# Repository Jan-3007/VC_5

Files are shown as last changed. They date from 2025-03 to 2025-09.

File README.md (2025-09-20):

# Project VC 5

Note: This project is still under development.

finished parts:
- Firmware
- PC app (basic functionality)
- schematic

under development:
- 3D model for the case
- PC app (features for better useability)

future:
- support for Linux

## General description
The aim of this project is to create an external device, which allows the user to adjust the volume of various programs on a host PC. 

## Hardware
A number of rotaries are available as input (number set to 5 within the config file of this project) and LED's and displays to show any kind of status.
The schematic for the device can be found at _Harware/schematic_.
Note: Soldering Pads in the schematic might be 0.1 mm thick, still working on a solution.

## Software
The software consists of two parts.

### 1. Firmware
The firmware is written for the Raspberry Pi RP2040. It communicates via USB with the host PC. The firmware only transmits data from the rotaries to the host PC and executes commands from the host PC. These commands can for example set the color of the LED and change the content shown on the displays.

### 2. PC application
The PC application (only Windows) acts as the executing intelligence. It takes the data from the rotaries and processes it. The volume of five different audio channels is controlled. The application can also send commands to the device to e.g. set the LED color or write information on the displays.

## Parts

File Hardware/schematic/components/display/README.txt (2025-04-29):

Thanks to thmjpr
https://grabcad.com/library/1-3-oled-module-1

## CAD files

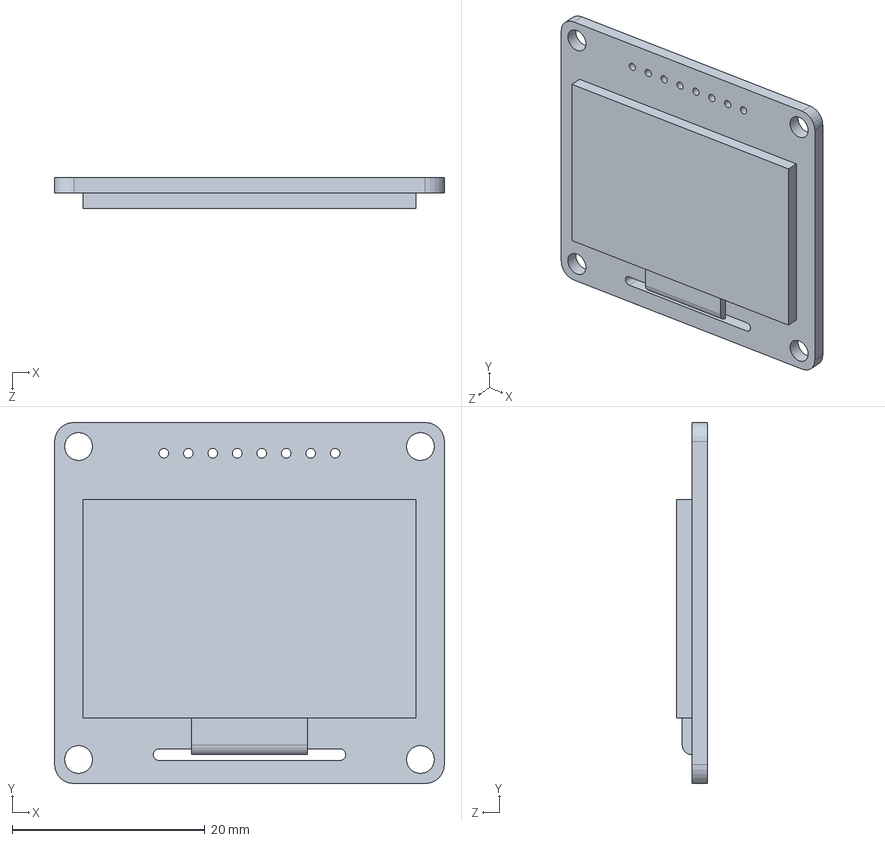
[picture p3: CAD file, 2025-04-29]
Hardware/schematic/components/display/OLED_pcb_1.3.SLDPRT
40.5 x 37.5 x 3.24 mm

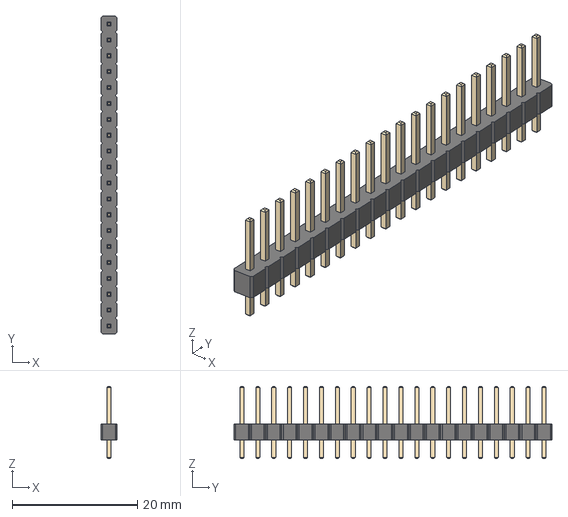
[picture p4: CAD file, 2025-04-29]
Hardware/schematic/components/pin_header/PinHeader_1x20_P2.54mm_Vertical.step
2.54 x 50.8 x 11.5 mm

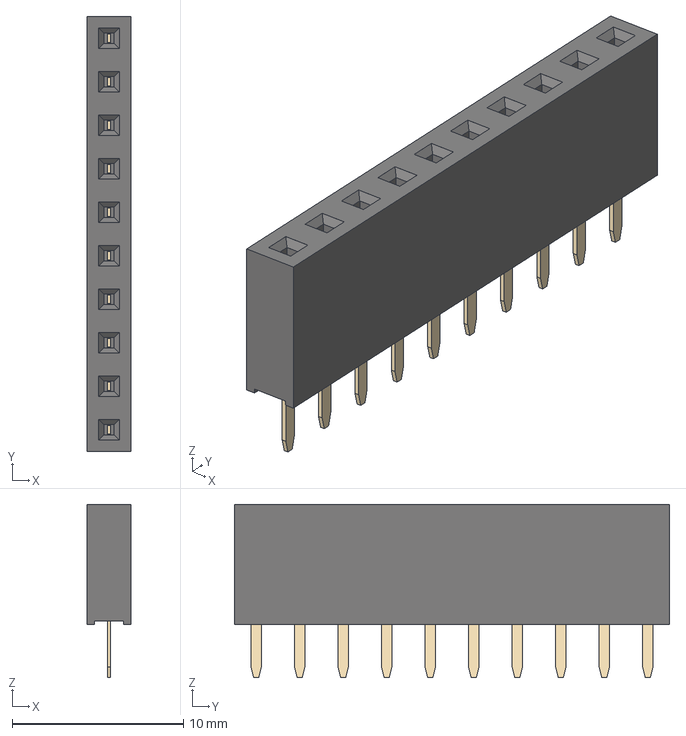
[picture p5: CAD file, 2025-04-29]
Hardware/schematic/components/pin_sockets/PinSocket_1x10_P2.54mm_Vertical.step
2.54 x 25.4 x 10.1 mm

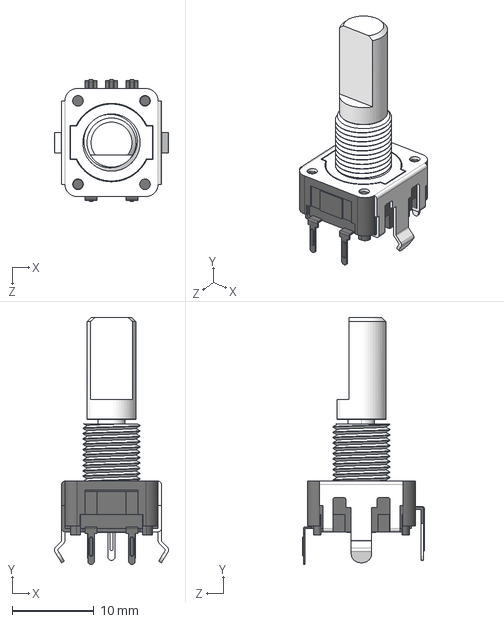
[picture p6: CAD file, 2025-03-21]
Hardware/schematic/components/rotary/PEC11R-4220F-S0024.stp
14.0 x 30.2 x 14.9 mm

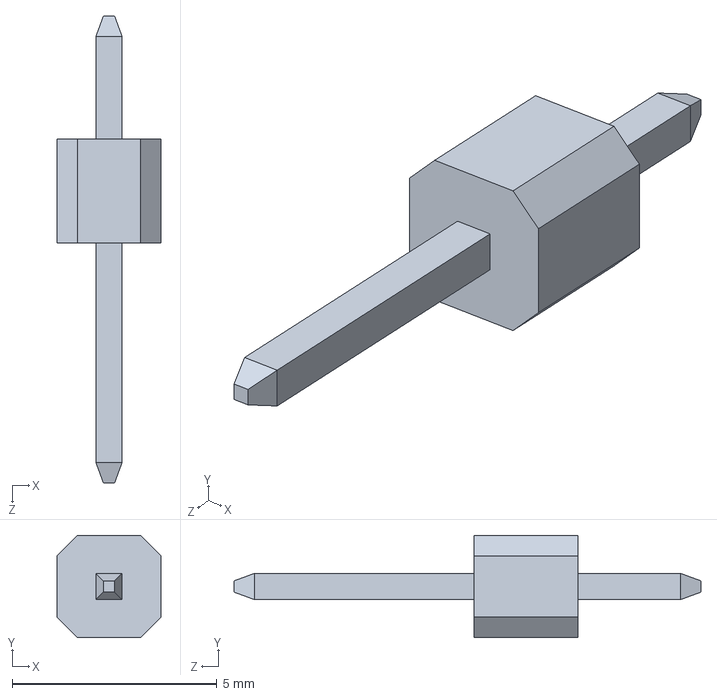
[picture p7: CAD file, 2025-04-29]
Hardware/schematic/components/display/2.54mm_pin_header.SLDPRT
2.54 x 2.50 x 11.4 mm

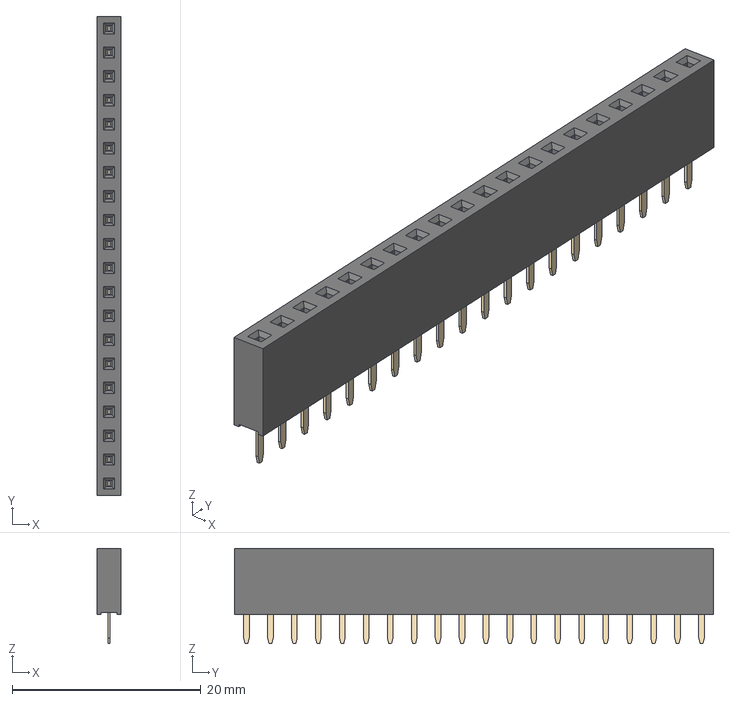
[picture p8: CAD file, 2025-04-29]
Hardware/schematic/components/pin_sockets/PinSocket_1x20_P2.54mm_Vertical.step
2.54 x 50.8 x 10.1 mm

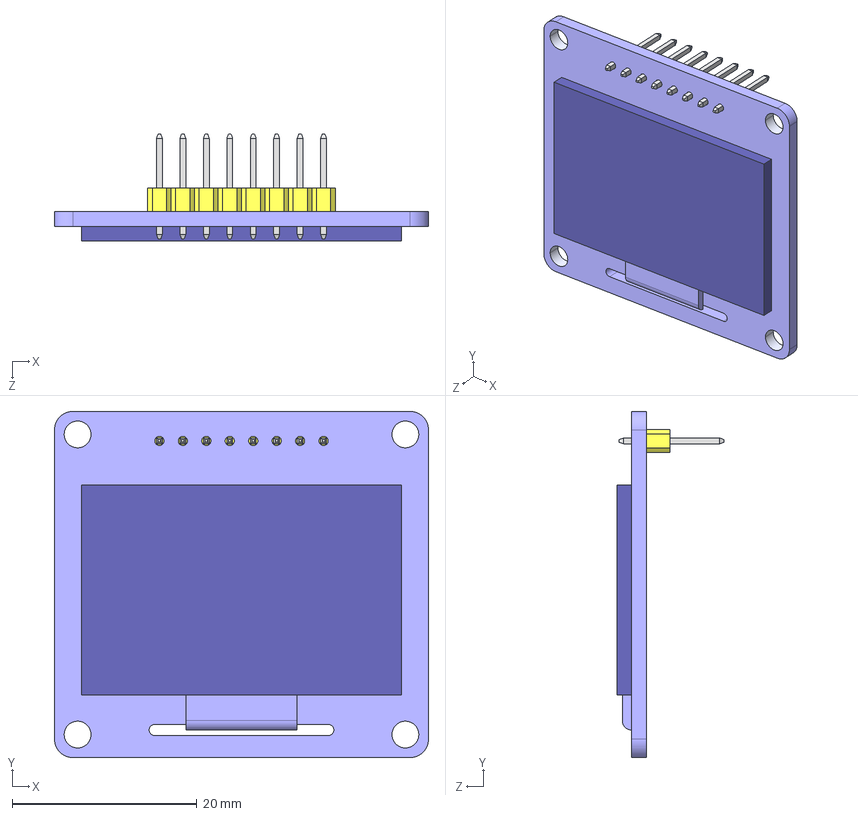
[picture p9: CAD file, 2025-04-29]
Hardware/schematic/components/display/OLED_1.3inch_sh1106.STEP
40.5 x 37.5 x 11.6 mm
OLED_pcb_1.3
2.54mm_pin_header x 8

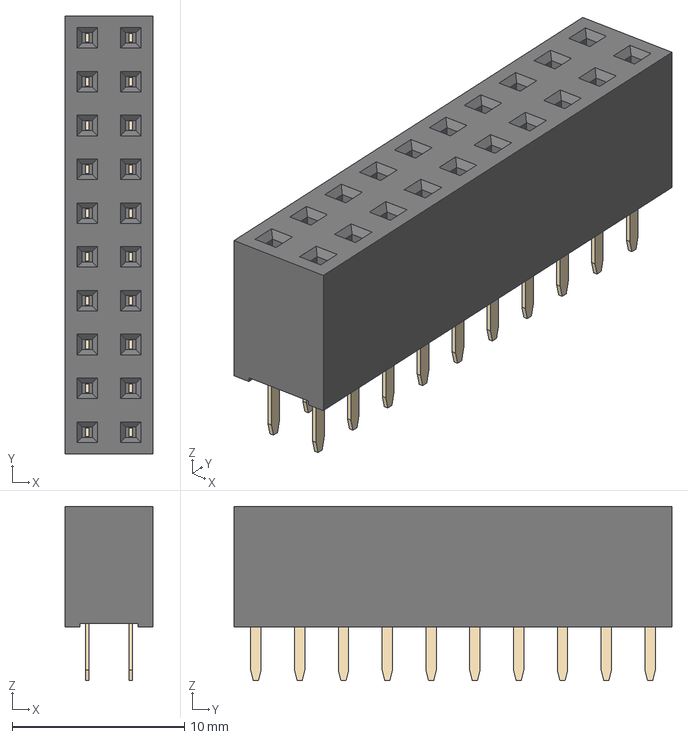
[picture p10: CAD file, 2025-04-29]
Hardware/schematic/components/pin_sockets/PinSocket_2x10_P2.54mm_Vertical.step
5.08 x 25.4 x 10.1 mm

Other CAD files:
Hardware/schematic/components/display/OLED_1.3inch_sh1106.SLDASM

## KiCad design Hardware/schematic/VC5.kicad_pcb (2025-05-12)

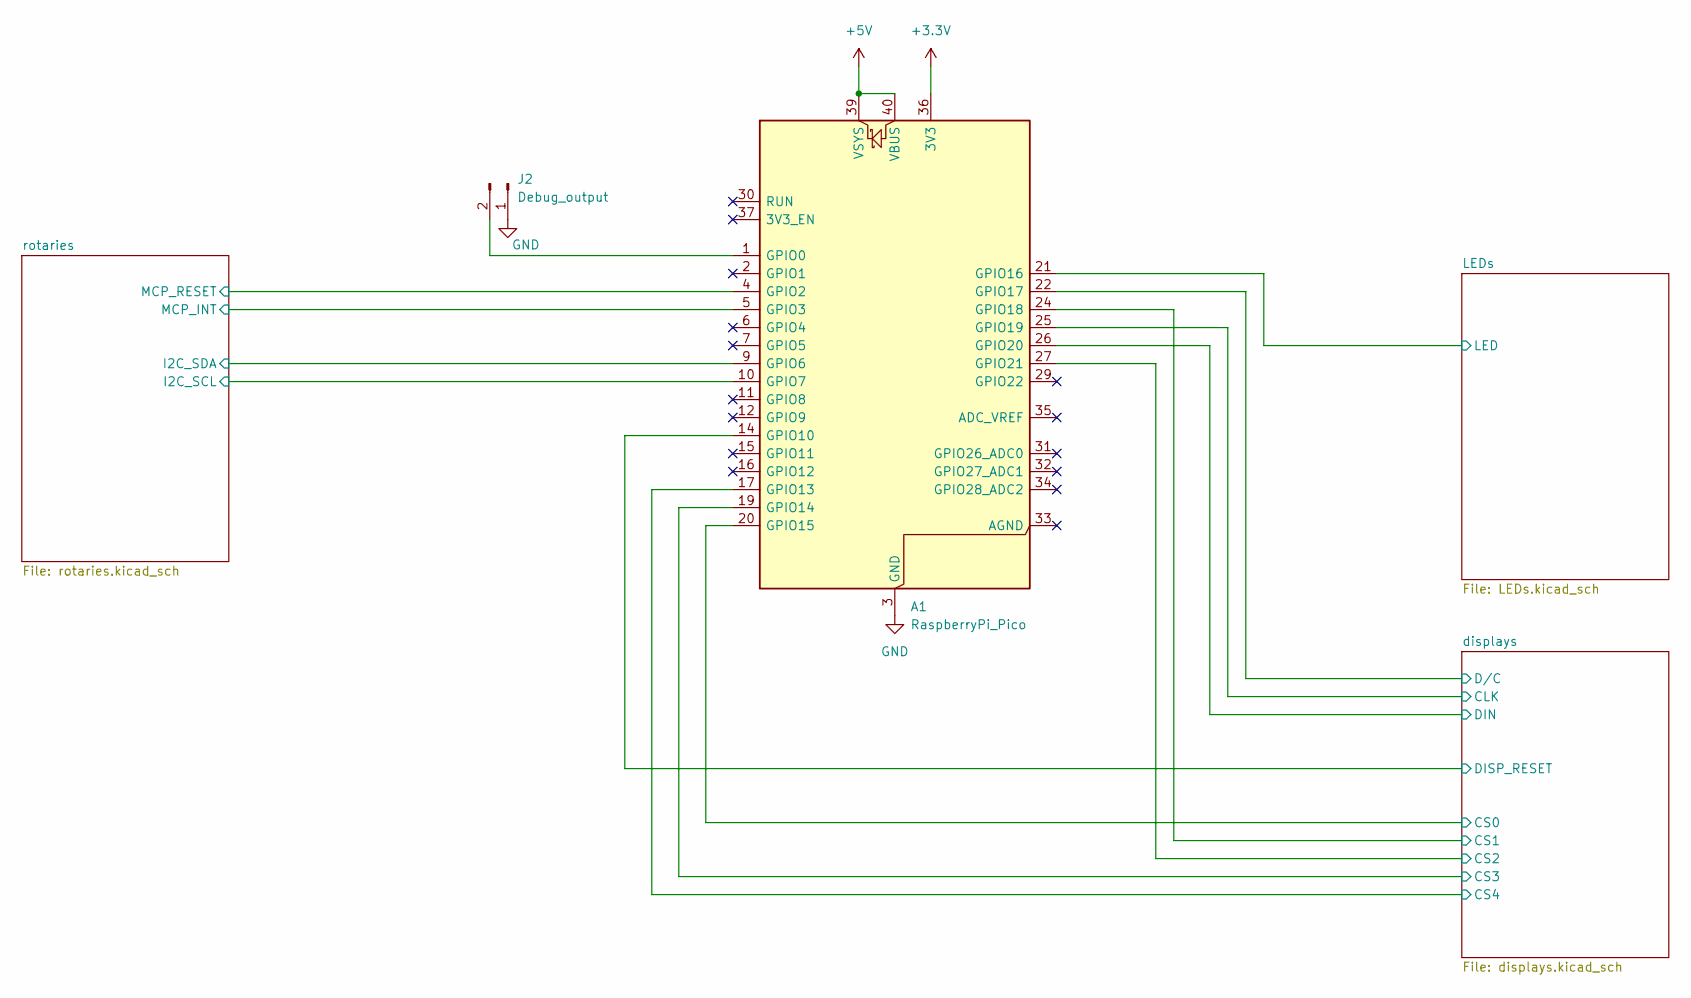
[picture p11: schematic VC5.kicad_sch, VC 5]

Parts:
A1: RaspberryPi_Pico; RaspberryPi_Pico_Common_THT_custom
J2: Debug_output; PinHeader_1x02_P2.54mm_Vertical

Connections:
+3.3V: A1.36 (3V3); also elsewhere on the board
+5V: A1.39 (VSYS), A1.40 (VBUS); also elsewhere on the board
/LEDs/LED: A1.21 (GPIO16); also elsewhere on the board
/displays/CLK: A1.25 (GPIO19); also elsewhere on the board
/displays/CS0: A1.20 (GPIO15); also elsewhere on the board
/displays/CS1: A1.24 (GPIO18); also elsewhere on the board
/displays/CS2: A1.27 (GPIO21); also elsewhere on the board
/displays/CS3: A1.19 (GPIO14); also elsewhere on the board
/displays/CS4: A1.17 (GPIO13); also elsewhere on the board
/displays/DIN: A1.26 (GPIO20); also elsewhere on the board
/displays/DISP_RESET: A1.14 (GPIO10); also elsewhere on the board
/displays/D/C: A1.22 (GPIO17); also elsewhere on the board
/rotaries/I2C_SCL: A1.10 (GPIO7); also elsewhere on the board
/rotaries/I2C_SDA: A1.9 (GPIO6); also elsewhere on the board
/rotaries/MCP_INT: A1.5 (GPIO3); also elsewhere on the board
/rotaries/MCP_RESET: A1.4 (GPIO2); also elsewhere on the board
GND: A1.3 (GND), A1.8 (GND), A1.13 (GND), A1.18 (GND), A1.23 (GND), A1.28 (GND), A1.38 (GND), J2.1; also elsewhere on the board
unnamed: A1.1 (GPIO0), J2.2

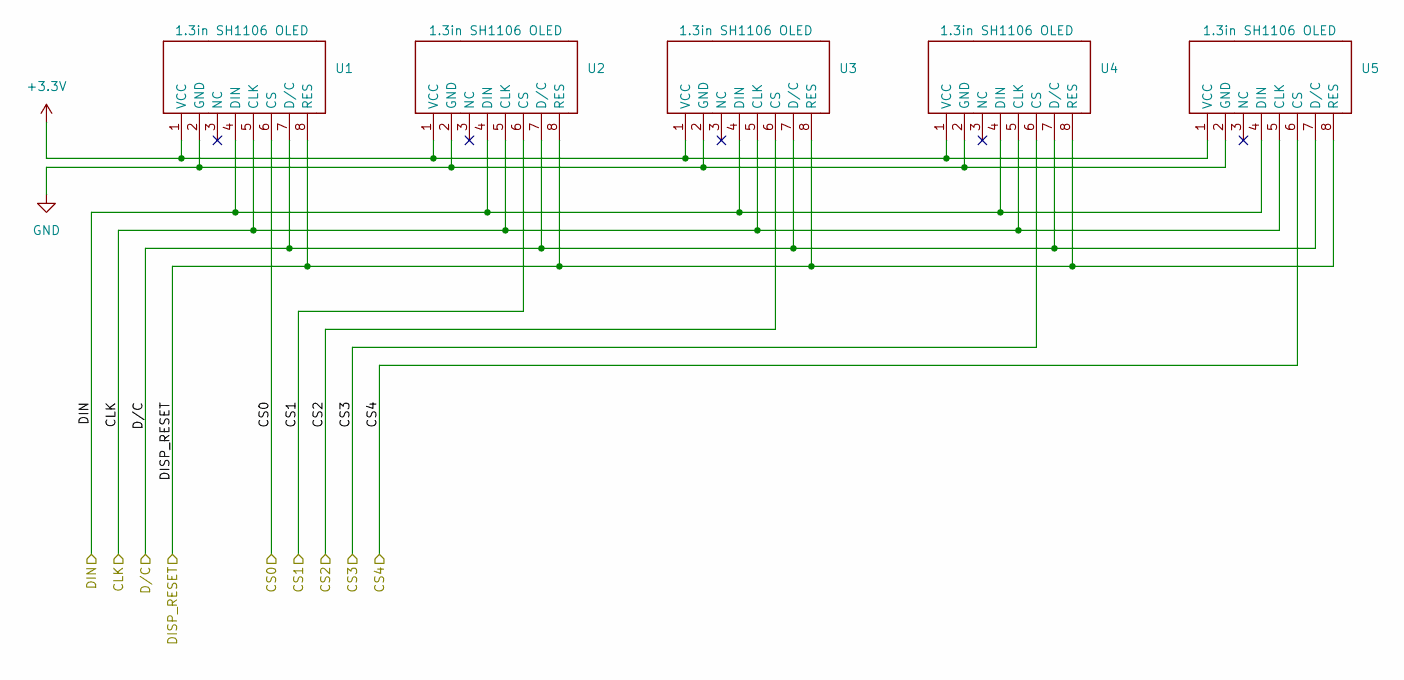
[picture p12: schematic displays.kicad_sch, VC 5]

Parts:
U1, U2, U3, U4, U5: 1.3in SH1106 OLED; PinHeader_1x08_P2.54mm_Vertical_Display

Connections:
+3.3V: U1.1 (VCC), U2.1 (VCC), U3.1 (VCC), U4.1 (VCC), U5.1 (VCC); also elsewhere on the board
/displays/CLK: U1.5 (CLK), U2.5 (CLK), U3.5 (CLK), U4.5 (CLK), U5.5 (CLK); also elsewhere on the board
/displays/CS0: U1.6 (CS); also elsewhere on the board
/displays/CS1: U2.6 (CS); also elsewhere on the board
/displays/CS2: U3.6 (CS); also elsewhere on the board
/displays/CS3: U4.6 (CS); also elsewhere on the board
/displays/CS4: U5.6 (CS); also elsewhere on the board
/displays/DIN: U1.4 (DIN), U2.4 (DIN), U3.4 (DIN), U4.4 (DIN), U5.4 (DIN); also elsewhere on the board
/displays/DISP_RESET: U1.8 (RES), U2.8 (RES), U3.8 (RES), U4.8 (RES), U5.8 (RES); also elsewhere on the board
/displays/D/C: U1.7 (D/C), U2.7 (D/C), U3.7 (D/C), U4.7 (D/C), U5.7 (D/C); also elsewhere on the board
GND: U1.2 (GND), U2.2 (GND), U3.2 (GND), U4.2 (GND), U5.2 (GND); also elsewhere on the board

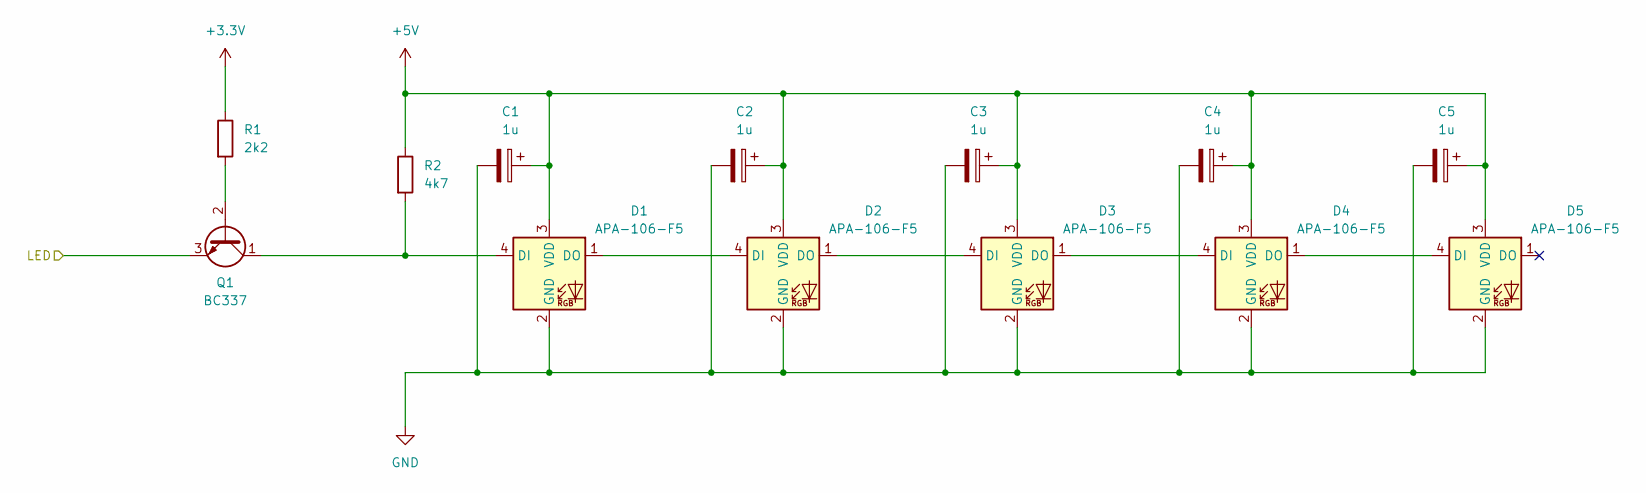
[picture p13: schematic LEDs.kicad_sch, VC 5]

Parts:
C1, C2, C3, C4, C5: 1u; CP_Radial_D5.0mm_P2.00mm
D1, D2, D3, D4, D5: APA-106-F5; LED_D5.0mm-4_RGB_Wide_Pins
Q1: BC337; TO-92_Inline
R1: 2k2; R_Axial_DIN0204_L3.6mm_D1.6mm_P7.62mm_Horizontal
R2: 4k7; R_Axial_DIN0204_L3.6mm_D1.6mm_P7.62mm_Horizontal

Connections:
+3.3V: R1.1; also elsewhere on the board
+5V: C1.1, C2.1, C3.1, C4.1, C5.1, D1.3 (VDD), D2.3 (VDD), D3.3 (VDD), D4.3 (VDD), D5.3 (VDD), R2.1; also elsewhere on the board
/LEDs/LED: Q1.3 (E); also elsewhere on the board
GND: C1.2, C2.2, C3.2, C4.2, C5.2, D1.2 (GND), D2.2 (GND), D3.2 (GND), D4.2 (GND), D5.2 (GND); also elsewhere on the board
unnamed: D1.4 (DI), Q1.1 (C), R2.2
unnamed: D1.1 (DO), D2.4 (DI)
unnamed: D2.1 (DO), D3.4 (DI)
unnamed: D3.1 (DO), D4.4 (DI)
unnamed: D4.1 (DO), D5.4 (DI)
unnamed: Q1.2 (B), R1.2

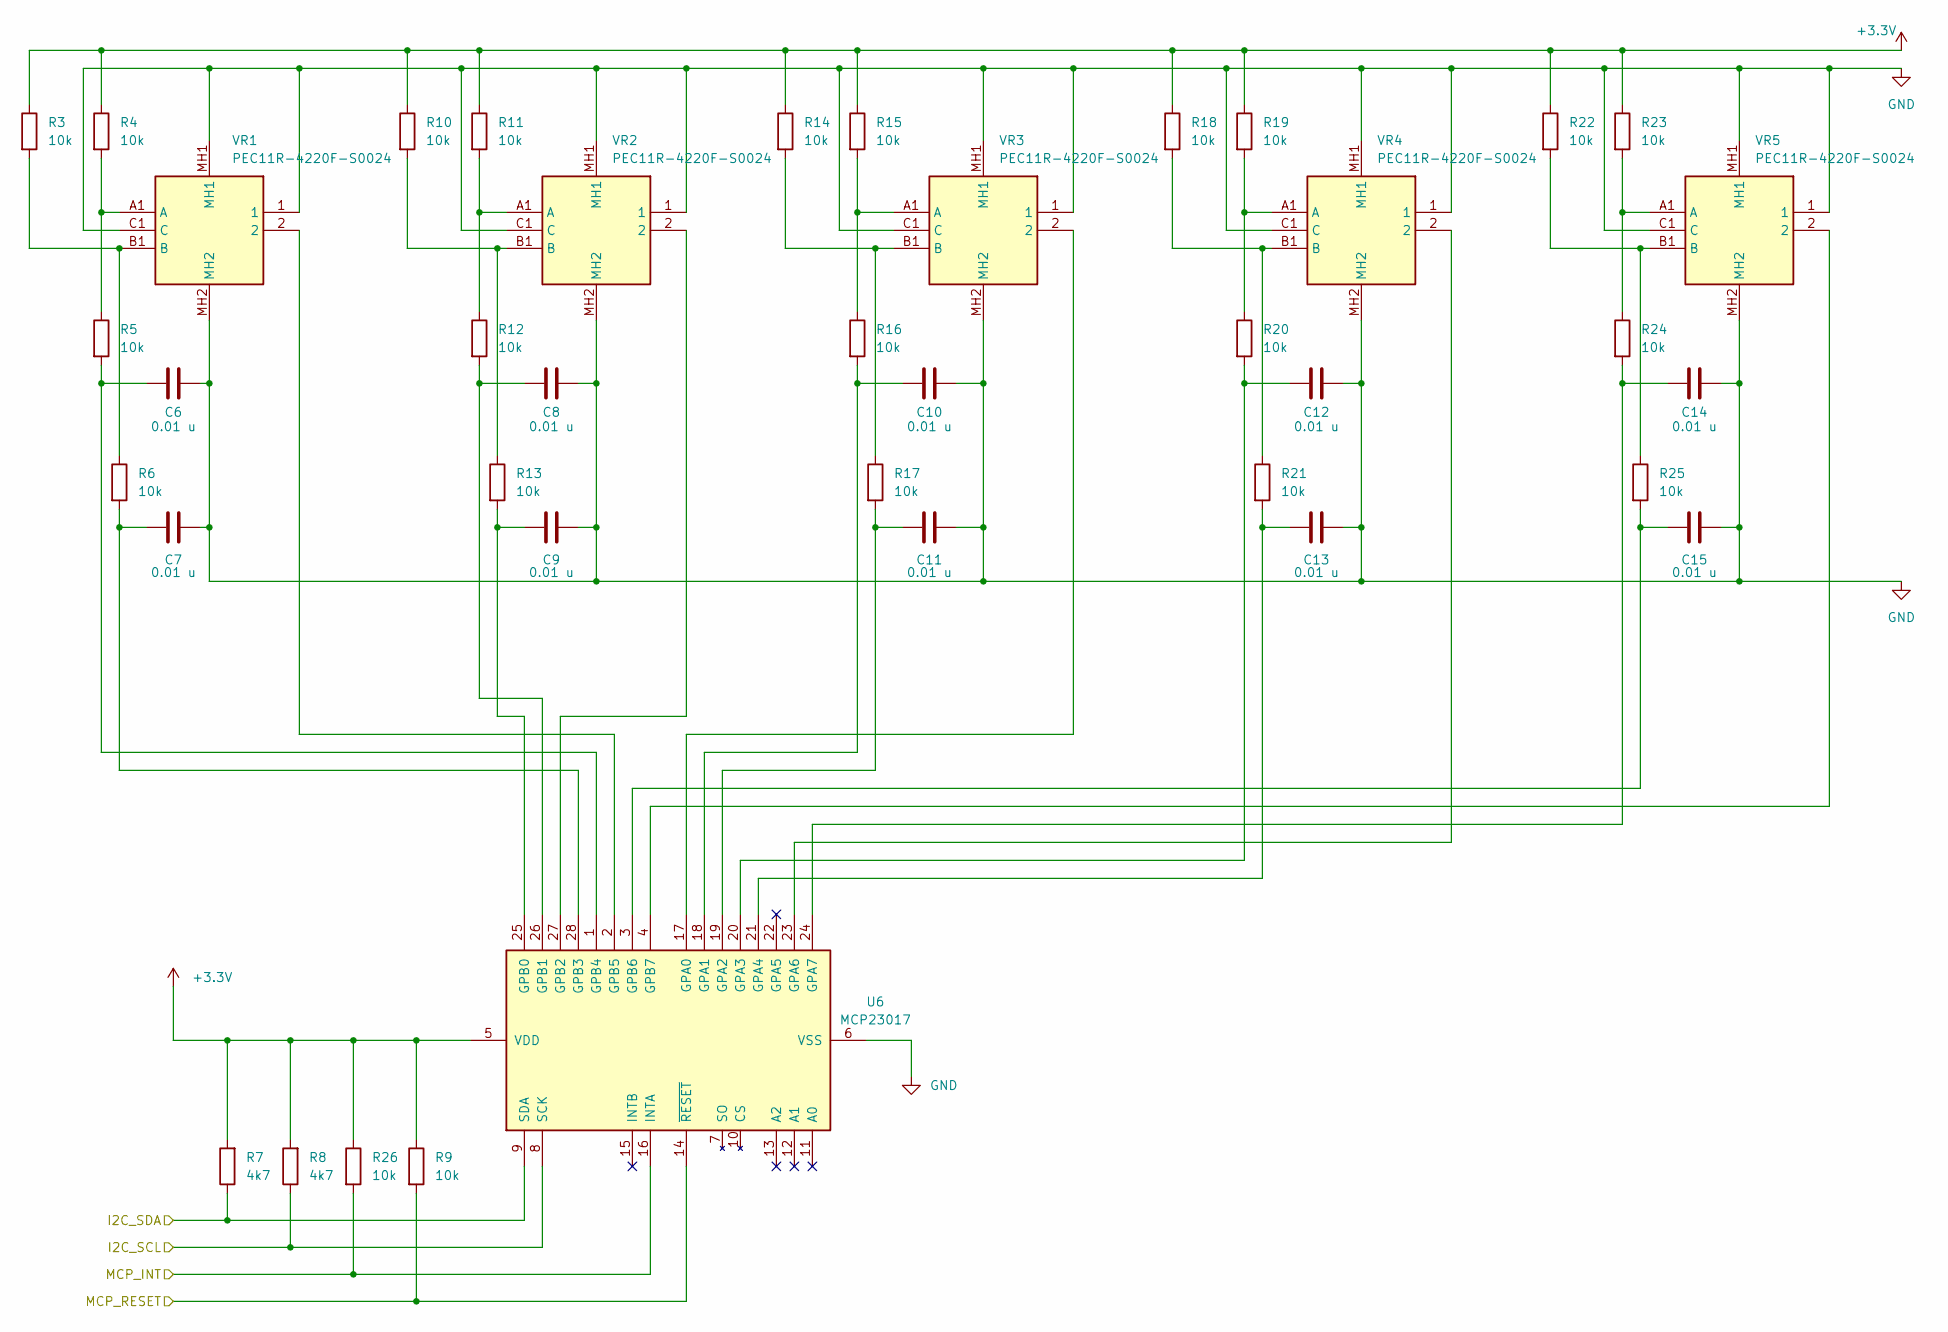
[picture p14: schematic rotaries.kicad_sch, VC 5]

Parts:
C6, C7, C8, C9, C10, C11, C12, C13, C14, C15: 0.01 u; C_Disc_D5.0mm_W2.5mm_P2.50mm
R3, R4, R5, R6, R9, R10, R11, R12, R13, R14, R15, R16, R17, R18, R19, R20, R21, R22, R23, R24, R25, R26: 10k; R_Axial_DIN0204_L3.6mm_D1.6mm_P7.62mm_Horizontal
R7, R8: 4k7; R_Axial_DIN0204_L3.6mm_D1.6mm_P7.62mm_Horizontal
U6: MCP23017; MCP23017_IO_expander
VR1, VR2, VR3, VR4, VR5: PEC11R-4220F-S0024; PEC11R4220FS0024; Manufacturer_Part_Number PEC11R-4220F-S0024; Mouser Part Number 652-PEC11R-4220F-S24

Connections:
+3.3V: R3.1, R4.1, R7.2, R8.2, R9.1, R10.1, R11.1, R14.1, R15.1, R18.1, R19.1, R22.1, R23.1, R26.1, U6.5 (VDD); also elsewhere on the board
/rotaries/I2C_SCL: R8.1, U6.8 (SCK); also elsewhere on the board
/rotaries/I2C_SDA: R7.1, U6.9 (SDA); also elsewhere on the board
/rotaries/MCP_INT: R26.2, U6.16 (INTA); also elsewhere on the board
/rotaries/MCP_RESET: R9.2, U6.14 (~RESET); also elsewhere on the board
GND: C6.2, C7.2, C8.2, C9.2, C10.2, C11.2, C12.2, C13.2, C14.2, C15.2, U6.6 (VSS), VR1.1, VR1.C1 (C), VR1.MH1, VR1.MH2, VR2.1, VR2.C1 (C), VR2.MH1, VR2.MH2, VR3.1, VR3.C1 (C), VR3.MH1, VR3.MH2, VR4.1, VR4.C1 (C), VR4.MH1, VR4.MH2, VR5.1, VR5.C1 (C), VR5.MH1, VR5.MH2; also elsewhere on the board
unnamed: U6.17 (GPA0), VR3.2
unnamed: C10.1, R16.2, U6.18 (GPA1)
unnamed: C11.1, R17.2, U6.19 (GPA2)
unnamed: C12.1, R20.2, U6.20 (GPA3)
unnamed: C13.1, R21.2, U6.21 (GPA4)
unnamed: U6.23 (GPA6), VR4.2
unnamed: C14.1, R24.2, U6.24 (GPA7)
unnamed: C9.1, R13.2, U6.25 (GPB0)
unnamed: C8.1, R12.2, U6.26 (GPB1)
unnamed: U6.27 (GPB2), VR2.2
unnamed: C7.1, R6.2, U6.28 (GPB3)
unnamed: C6.1, R5.2, U6.1 (GPB4)
unnamed: U6.2 (GPB5), VR1.2
unnamed: C15.1, R25.2, U6.3 (GPB6)
unnamed: U6.4 (GPB7), VR5.2
unnamed: R4.2, R5.1, VR1.A1 (A)
unnamed: R3.2, R6.1, VR1.B1 (B)
unnamed: R11.2, R12.1, VR2.A1 (A)
unnamed: R10.2, R13.1, VR2.B1 (B)
unnamed: R15.2, R16.1, VR3.A1 (A)
unnamed: R14.2, R17.1, VR3.B1 (B)
unnamed: R19.2, R20.1, VR4.A1 (A)
unnamed: R18.2, R21.1, VR4.B1 (B)
unnamed: R23.2, R24.1, VR5.A1 (A)
unnamed: R22.2, R25.1, VR5.B1 (B)

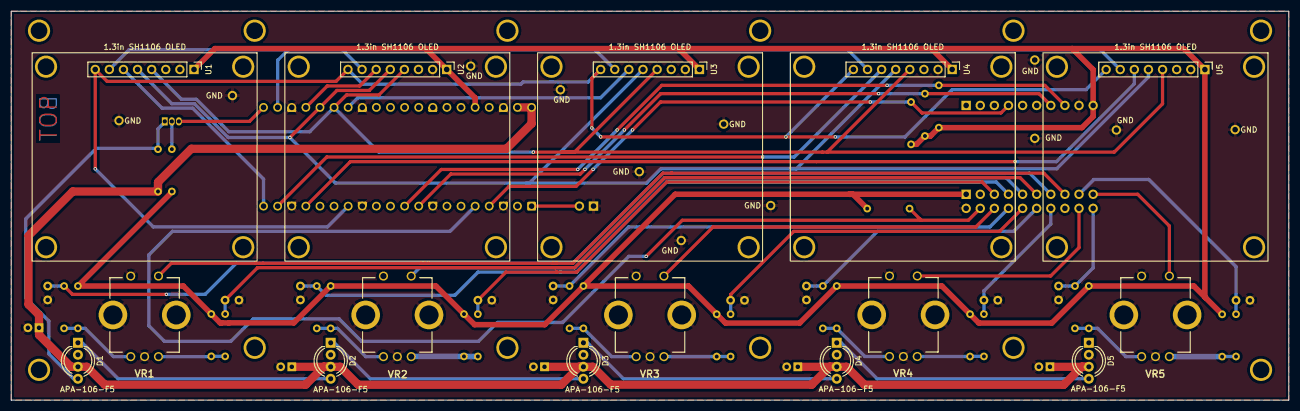
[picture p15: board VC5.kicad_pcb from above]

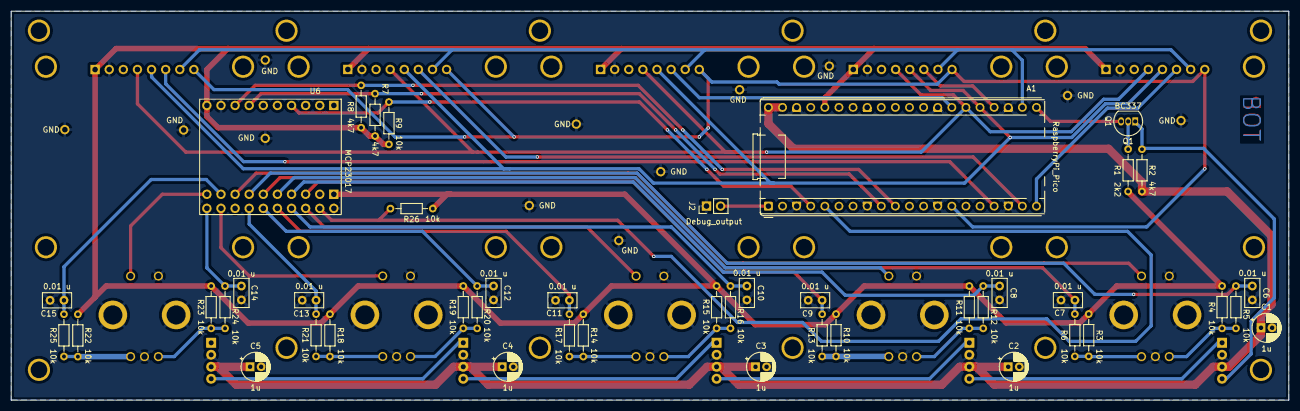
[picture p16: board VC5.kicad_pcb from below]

Board: 2 copper layers, 230.0 x 70.0 mm, 60 parts (45 on the bottom side), 49 nets.

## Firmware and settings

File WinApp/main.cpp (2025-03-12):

#include "VC5_global.h"





int
main()
{
	WinError err = NO_ERROR;

	VC5Application app;

	err = app.init_WinUSB();
	err = app.init_led();
	err = app.init_displays();


	std::cout << std::format("Reading events ... press any key to exit.\n");

	while (true)
	{
		err = app.check_event();
		if (err != NO_ERROR)
		{
			return -1;
		}


		if (_kbhit())
		{
			_getch();
			break;
		}

		Sleep(100);
	}


	return 0;
}

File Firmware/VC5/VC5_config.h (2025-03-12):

#pragma once



//-----------------------------------------------------------
// VC 5 - General
//-----------------------------------------------------------

constexpr uint32_t c_num_units = 5;         // 1 unit = 1 rotary + 1 display + 1 LED



//-----------------------------------------------------------
// Raspberry Pi Pico - Pins
//-----------------------------------------------------------

// Rotaries
constexpr uint32_t c_i2c_sda_pin = 6;
constexpr uint32_t c_i2c_scl_pin = 7;
constexpr uint32_t c_mcp_int_pin = 3;

// LEDs
constexpr uint32_t c_led_pin = 20;

// Displays
constexpr int c_spi_data_pin = 19;
constexpr int c_spi_clk_pin = 18;
constexpr int c_spi_dc_pin = 16;
constexpr int c_disp_reset_pin = 10;

constexpr int c_spi_cs0_pin = 12;
constexpr int c_spi_cs1_pin = 13;
constexpr int c_spi_cs2_pin = 14;
constexpr int c_spi_cs3_pin = 17;
constexpr int c_spi_cs4_pin = 15;




//-----------------------------------------------------------
// Raspberry Pi Pico - I²C
//-----------------------------------------------------------

#define I2C_PORT i2c1
// freq = 400 kHz
constexpr int32_t c_i2c_freq_hz = 400 * 1000;


//-----------------------------------------------------------
// Raspberry Pi Pico - SPI
//-----------------------------------------------------------
#define SPI_PORT spi0
// freq = 1 MHz
constexpr int c_spi_freq_hz = 1000 * 1000;



//-----------------------------------------------------------
// FreeRTOS
//-----------------------------------------------------------

// RP2040 SRAM size: 264kB on-chip
// Pico Flash size: 2MB on-board

namespace task_rotaries
{
    const char name[] = "ROT";
    constexpr uint32_t c_prio = configMAX_PRIORITIES - 1u;
    constexpr uint32_t c_stack_size_bytes = 1024;
    constexpr uint32_t c_stack_size_words = c_stack_size_bytes / 4;
}

namespace task_usb
{
    const char name[] = "USB";
    constexpr uint32_t c_prio = configMAX_PRIORITIES - 2u;
    constexpr uint32_t c_stack_size_bytes = 4096;
    constexpr uint32_t c_stack_size_words = c_stack_size_bytes / 4;

    constexpr uint32_t c_usb_task_interval_ms = 10;
}



//-----------------------------------------------------------
// Rotaries + MCP23017
//-----------------------------------------------------------

struct rotary_pins_mask
{
    uint16_t clk_mask {0};
    uint16_t data_mask {0};
    uint16_t button_mask {0};
};

//
// rotary masks
//                               clk,       data,      button
constexpr rotary_pins_mask rot_0 {(1u << 1), (1u << 0), (1u << 2)};
constexpr rotary_pins_mask rot_1 {(1u << 4), (1u << 5), (1u << 3)};
constexpr rotary_pins_mask rot_2 {(1u << 15), (1u << 7), (1u << 6)};
constexpr rotary_pins_mask rot_3 {(1u << 10), (1u << 9), (1u << 14)};
constexpr rotary_pins_mask rot_4 {(1u << 12), (1u << 11), (1u << 13)};


constexpr uint32_t c_num_rotaries = c_num_units;


constexpr uint32_t c_debounce_threshold = 2;
constexpr uint32_t c_debounce_delay_ms = 1;



//-----------------------------------------------------------
// WS2812 LEDs
//-----------------------------------------------------------

constexpr uint32_t c_num_leds = c_num_units;

// RGB, 8 bit for each color 
constexpr uint32_t c_color_bit_depth = 8;
constexpr uint32_t c_num_colors_per_led = 3;
constexpr uint32_t c_bytes_per_led = (c_color_bit_depth * c_num_colors_per_led) / 8;



//-----------------------------------------------------------
// Waveshare 1.3 inch OLED blue on black display
//-----------------------------------------------------------

constexpr uint32_t c_num_displays = c_num_units;

struct display_properties
{
    uint32_t cs_pin;
    uint32_t width;
    uint32_t height;
};


#define USE_WAVESHARE_1IN3_OLED
#ifdef USE_WAVESHARE_1IN3_OLED

// different display sizes is not supported
constexpr uint32_t c_display_width = 128;
constexpr uint32_t c_display_height = 64;
constexpr uint32_t c_display_size = c_display_width * c_display_height;

//                                  cs_pin,             width,              height
constexpr display_properties disp_0 {c_spi_cs0_pin,     c_display_width,    c_display_height};
constexpr display_properties disp_1 {c_spi_cs1_pin,     c_display_width,    c_display_height};
constexpr display_properties disp_2 {c_spi_cs2_pin,     c_display_width,    c_display_height};
constexpr display_properties disp_3 {c_spi_cs3_pin,     c_display_width,    c_display_height};
constexpr display_properties disp_4 {c_spi_cs4_pin,     c_display_width,    c_display_height};

// default image rotation 
constexpr uint16_t c_image_rotation = ROTATE_270;
// default font for text
constexpr sFONT* c_display_font = &Font12;

#endif

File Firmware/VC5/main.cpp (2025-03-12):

#include "VC5_global.h"



#ifdef __cplusplus
extern "C"
#endif
void fatal_error(int reason)
{
    printf("FATAL ERROR: reason %d", reason);

    while(true);
}



int main()
{
    stdio_init_all();
    printf("VC 5: %s %s\n", __DATE__, __TIME__);

    init_i2c();
    init_spi();

    // init and task setup for the rotaries
    init_rotaries();

    // init PIO for LEDs
    init_led_chain();

    // init displays
    init_displays();

    // init and task setup for USB
    init_usb();



    /* Start the scheduler. */
    vTaskStartScheduler();

    for( ; ; )
    {
        /* Should not reach here. */
    }

    return 0;
}

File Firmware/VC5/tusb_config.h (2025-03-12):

/*
 * The MIT License (MIT)
 *
 * Copyright (c) 2019 Ha Thach (tinyusb.org)
 *
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
 */

#ifndef _TUSB_CONFIG_H_
#define _TUSB_CONFIG_H_

#include <assert.h>

#ifdef __cplusplus
 extern "C" {
#endif

//--------------------------------------------------------------------
// COMMON CONFIGURATION
//--------------------------------------------------------------------

// CFG_TUSB_DEBUG for debugging
// 0 : no debug
// 1 : print error
// 2 : print warning
// 3 : print info
#define CFG_TUSB_DEBUG  1


// defined by board.mk
#ifndef CFG_TUSB_MCU
  #error CFG_TUSB_MCU must be defined
#endif

// RHPort number used for device can be defined by board.mk, default to port 0
#ifndef BOARD_DEVICE_RHPORT_NUM
  #define BOARD_DEVICE_RHPORT_NUM     0
#endif

// RHPort max operational speed can defined by board.mk
// Default to Highspeed for MCU with internal HighSpeed PHY (can be port specific), otherwise FullSpeed
#ifndef BOARD_DEVICE_RHPORT_SPEED
  #if (CFG_TUSB_MCU == OPT_MCU_LPC18XX || CFG_TUSB_MCU == OPT_MCU_LPC43XX || CFG_TUSB_MCU == OPT_MCU_MIMXRT10XX || \
       CFG_TUSB_MCU == OPT_MCU_NUC505  || CFG_TUSB_MCU == OPT_MCU_CXD56 || CFG_TUSB_MCU == OPT_MCU_SAMX7X)
    #define BOARD_DEVICE_RHPORT_SPEED   OPT_MODE_HIGH_SPEED
  #else
    #define BOARD_DEVICE_RHPORT_SPEED   OPT_MODE_FULL_SPEED
  #endif
#endif

// Device mode with rhport and speed defined by board.mk
#if   BOARD_DEVICE_RHPORT_NUM == 0
  #define CFG_TUSB_RHPORT0_MODE     (OPT_MODE_DEVICE | BOARD_DEVICE_RHPORT_SPEED)
#elif BOARD_DEVICE_RHPORT_NUM == 1
  #define CFG_TUSB_RHPORT1_MODE     (OPT_MODE_DEVICE | BOARD_DEVICE_RHPORT_SPEED)
#else
  #error "Incorrect RHPort configuration"
#endif

#ifndef CFG_TUSB_OS
#define CFG_TUSB_OS               OPT_OS_NONE
#endif


/* USB DMA on some MCUs can only access a specific SRAM region with restriction on alignment.
 * Tinyusb use follows macros to declare transferring memory so that they can be put
 * into those specific section.
 * e.g
 * - CFG_TUSB_MEM SECTION : __attribute__ (( section(".usb_ram") ))
 * - CFG_TUSB_MEM_ALIGN   : __attribute__ ((aligned(4)))
 */
#ifndef CFG_TUSB_MEM_SECTION
#define CFG_TUSB_MEM_SECTION
#endif

#ifndef CFG_TUSB_MEM_ALIGN
#define CFG_TUSB_MEM_ALIGN          __attribute__ ((aligned(4)))
#endif

//--------------------------------------------------------------------
// DEVICE CONFIGURATION
//--------------------------------------------------------------------

#ifndef CFG_TUD_ENDPOINT0_SIZE
#define CFG_TUD_ENDPOINT0_SIZE    64
#endif

//------------- CLASS -------------//
#define CFG_TUD_HID               0
#define CFG_TUD_CDC               0
#define CFG_TUD_MSC               0
#define CFG_TUD_MIDI              0
#define CFG_TUD_VENDOR            2


// for Vendor interfaces
#define CFG_TUD_VENDOR_RX_BUFSIZE   64
#define CFG_TUD_VENDOR_TX_BUFSIZE   64


#ifdef __cplusplus
 }
#endif

#endif /* _TUSB_CONFIG_H_ */

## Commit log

2025-03-21 added schematic files
    [LEDs.kicad_sch, PEC11R-4220F-S0024.stp, VC5.kicad_pcb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]
2025-03-21 fixed missing schematic symbols
    [displays.kicad_sch]
2025-04-20 fixed an error in the filters for the rotaries
    [LEDs.kicad_sch, VC5.kicad_pcb, VC5.kicad_sch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]
2025-04-29 updated footprints and corresponding 3D models
    [2.54mm_pin_header.SLDPRT, OLED_1.3inch_sh1106.SLDASM, OLED_1.3inch_sh1106.STEP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]
2025-04-30 added pcb parameters, positioned LEDs
    [VC5.kicad_pcb]
2025-05-05 trace routing completed
    [LEDs.kicad_sch, VC5.kicad_pcb, VC5.kicad_sch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]
2025-05-06 added final trace adjustments and mounting holes
    [VC5.kicad_pcb]
2025-05-06 first final version
    [VC5.kicad_pcb]
2025-05-08 updated PCB layout
    [LEDs.kicad_sch, displays.kicad_sch]
2025-05-08 fixed missing interrupt line
    [VC5.kicad_pcb, VC5.kicad_sch, rotaries.kicad_sch]
2025-05-12 final version of the PCB
    [VC5.kicad_pcb, rotaries.kicad_sch, trace_specs.ods]
2025-05-12 reorganized schematic files
    [2.54mm_pin_header.SLDPRT, LEDs.kicad_sch, OLED_1.3inch_sh1106.SLDASM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]
2025-05-12 removed KiCAD backups

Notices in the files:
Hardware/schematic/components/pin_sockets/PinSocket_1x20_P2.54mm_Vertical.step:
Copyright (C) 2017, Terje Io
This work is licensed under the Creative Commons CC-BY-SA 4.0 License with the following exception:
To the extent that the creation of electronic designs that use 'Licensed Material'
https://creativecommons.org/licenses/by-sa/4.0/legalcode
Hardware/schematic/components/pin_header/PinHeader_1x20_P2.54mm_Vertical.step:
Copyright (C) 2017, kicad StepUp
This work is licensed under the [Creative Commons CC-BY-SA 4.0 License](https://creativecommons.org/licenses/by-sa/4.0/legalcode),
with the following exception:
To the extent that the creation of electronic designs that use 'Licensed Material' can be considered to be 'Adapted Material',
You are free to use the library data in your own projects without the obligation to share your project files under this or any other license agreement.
